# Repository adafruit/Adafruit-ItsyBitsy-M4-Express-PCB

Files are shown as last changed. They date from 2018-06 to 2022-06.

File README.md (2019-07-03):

## Adafruit ItsyBitsy M4 Express PCB

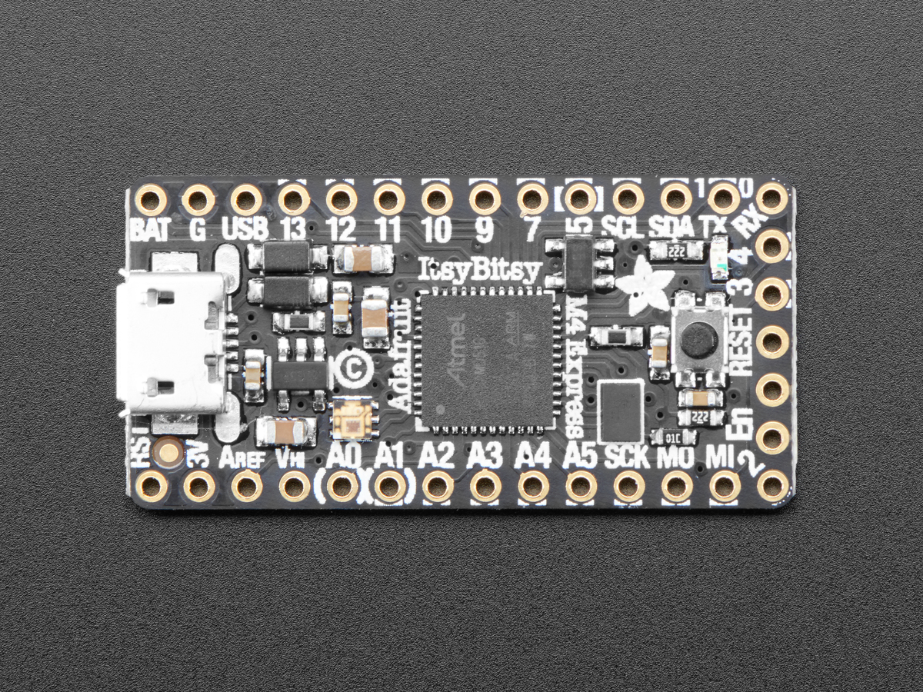
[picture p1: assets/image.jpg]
<a href="http://www.adafruit.com/products/3800"><br/>
Click here to purchase one from the Adafruit shop</a>

PCB files for the Adafruit ItsyBitsy M4 Express. PCB format is EagleCAD schematic and board layout

For more details, check out the product pages at
* https://www.adafruit.com/products/3800

### Description

What's smaller than a Feather but larger than a Trinket? It's an Adafruit ItsyBitsy M4 Express featuring the Microchip ATSAMD51! Small, powerful, with a ultra fast ATSAMD51 Cortex M4 processor running at 120 MHz - this microcontroller board is perfect when you want something very compact, with a ton of horsepower and a bunch of pins. This Itsy is like a bullet train, with it's 120MHz Cortex M4 with floating point support and 512KB Flash and 192KB RAM. Your code will zig and zag and zoom, and with a bunch of extra peripherals for support, this will for sure be your favorite new chipset.

ItsyBitsy M4 Express is only 1.4" long by 0.7" wide, but has 6 power pins, 23 digital GPIO pins (7 of which can be analog in, 2 x 1 MSPS analog out DACs, and 18 x PWM out). It's the same chip as the Adafruit Metro M4 but really really small. So it's great once you've finished up a prototype on a Metro M4 or (the upcoming) Feather M4, and want to make the project much smaller. It even comes with 2MB of SPI Flash built in, for data logging, file storage, or CircuitPython code.

The most exciting part of the ItsyBitsy M4 is that while you can use it with the Arduino IDE, we are shipping it with CircuitPython on board. When you plug it in, it will show up as a very small disk drive with main.py on it. Edit main.py with your favorite text editor to build your project using Python, the most popular programming language. No installs, IDE or compiler needed, so you can use it on any computer, even ChromeBooks or computers you can't install software on. When you're done, unplug the Itsy' and your code will go with you.

### License

Adafruit invests time and resources providing this open source design, please support Adafruit and open-source hardware by purchasing products from [Adafruit](https://www.adafruit.com)!

Designed by Limor Fried/Ladyada for Adafruit Industries.

Creative Commons Attribution/Share-Alike, all text above must be included in any redistribution. See license.txt for additional details.

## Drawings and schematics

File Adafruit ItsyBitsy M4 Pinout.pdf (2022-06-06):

# Adafruit ItsyBitsy M4

# https://www.adafruit.com/product/3800

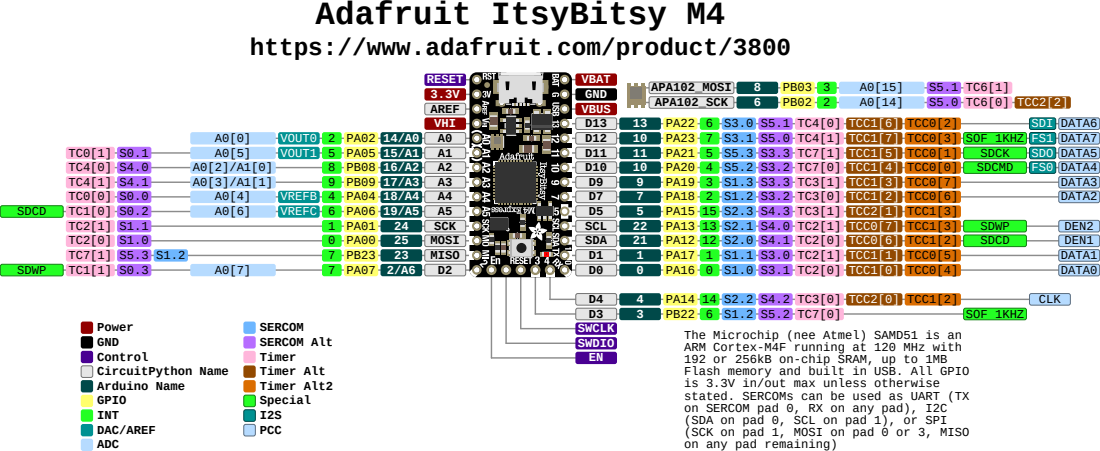
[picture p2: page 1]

The Microchip (nee Atmel) SAMD51 is an
ARM Cortex-M4F running at 120 MHz with
192 or 256kB on-chip SRAM, up to 1MB
Flash memory and built in USB. All GPIO
is 3.3V in/out max unless otherwise
stated. SERCOMs can be used as UART (TX
on SERCOM pad 0, RX on any pad), I2C
(SDA on pad 0, SCL on pad 1), or SPI
(SCK on pad 1, MOSI on pad 0 or 3, MISO
on any pad remaining)

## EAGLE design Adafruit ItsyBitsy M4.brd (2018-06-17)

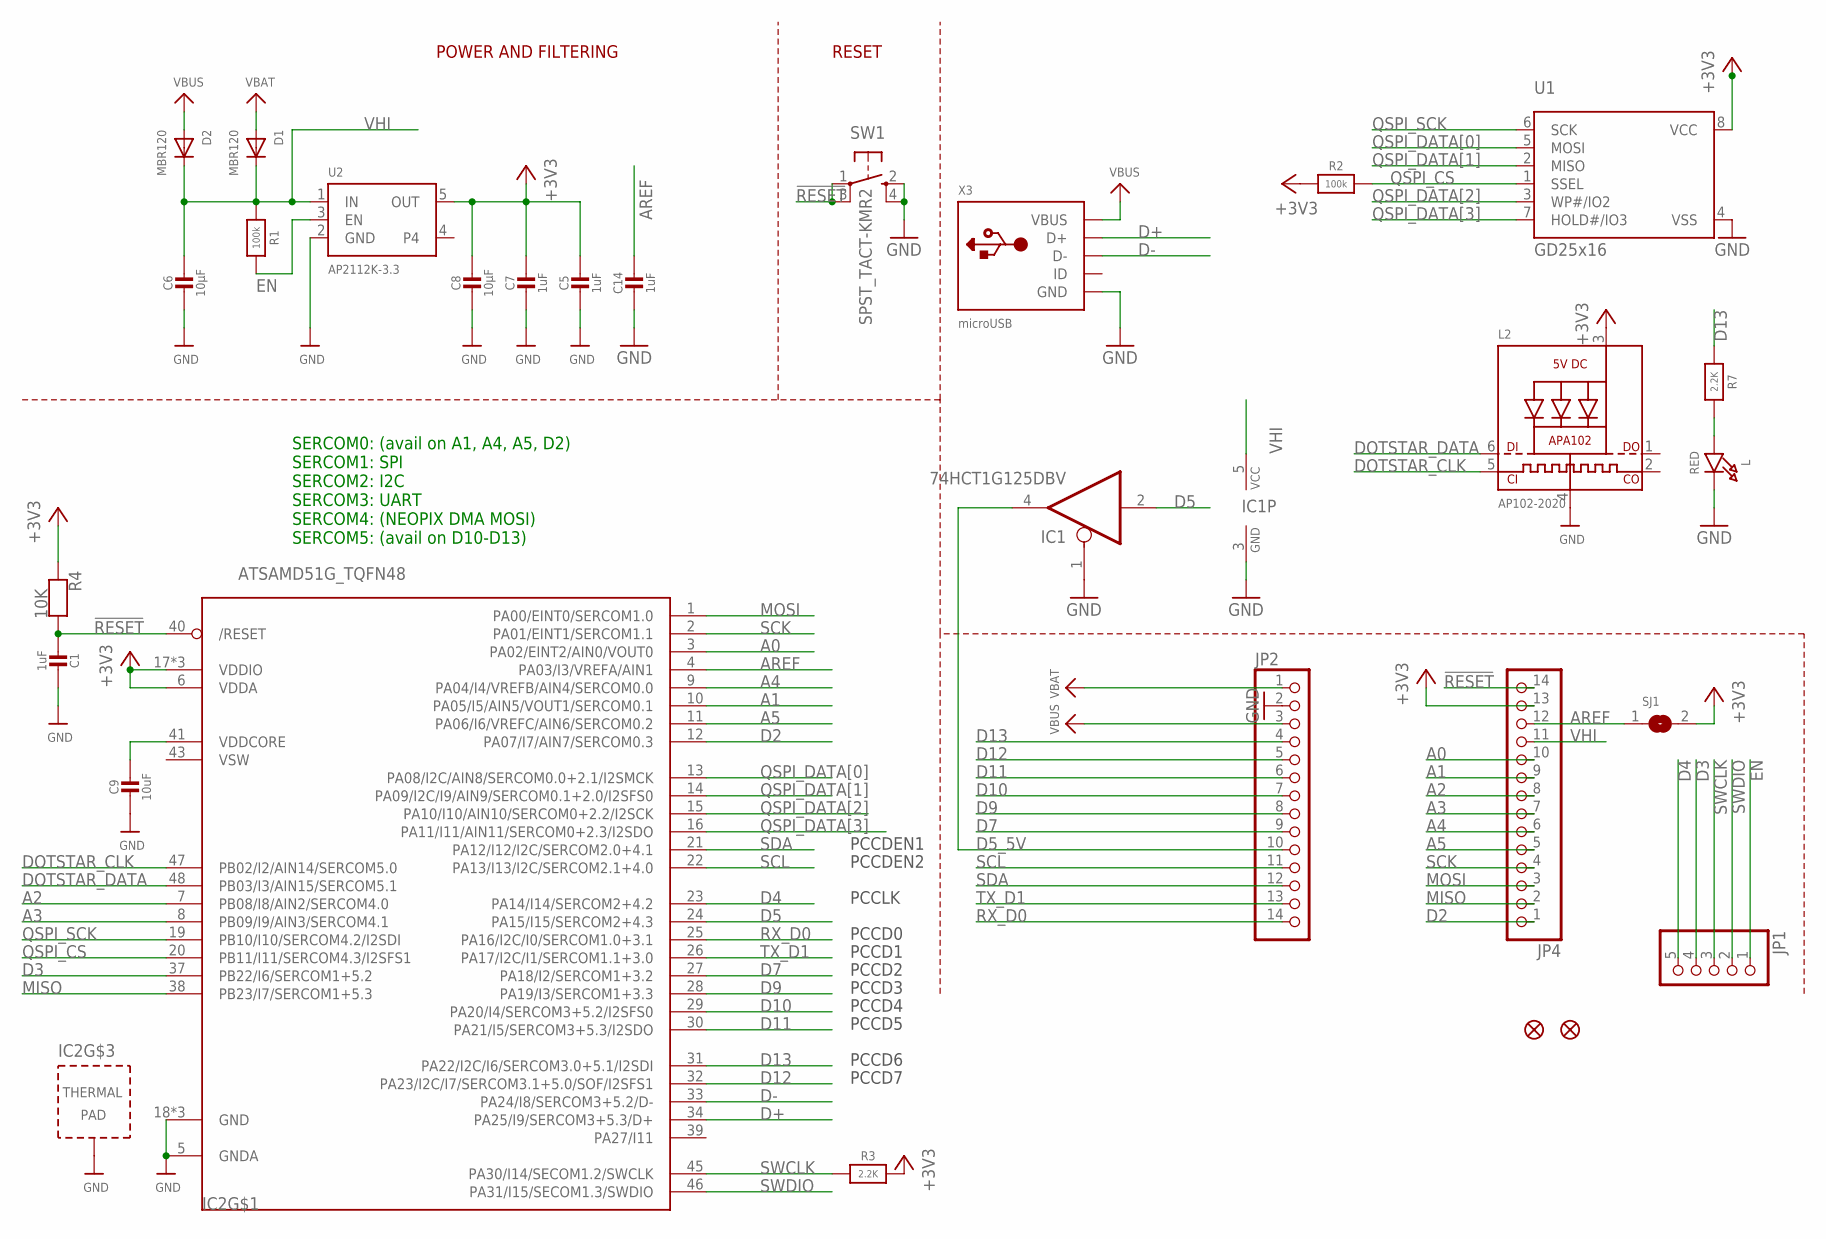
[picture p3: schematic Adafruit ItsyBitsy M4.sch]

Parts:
C1: 1uF; _0603MP
C5, C7, C14: 1uF; 0603-NO
C6, C8: 10µF; 0805-NO
C9: 10uF; _0805MP
D1, D2: MBR120; SOD-123FL
IC1: 74HCT1G125DBV; SOT23-5
IC2: ATSAMD51G_TQFN48; TQFN48_7MM
JP1: HEADER-1X570MIL; 1X05_ROUND_70
JP2, JP4: HEADER-1X14; 1X14_ROUND70
L: RED; CHIPLED_0603_NOOUTLINE
L2: AP102-2020; APA102_2020
R1, R2: 100k; 0603-NO
R3: 2.2K; _0603MP
R4: 10K; _0603MP
R7: 2.2K; 0603-NO
SJ1: SOLDERJUMPERCLOSED; SOLDERJUMPER_CLOSEDWIRE
SW1: SPST_TACT-KMR2; KMR2
U1: GD25x16; USON8
U2: AP2112K-3.3; SOT23-5
U$34, U$35: FIDUCIAL_1MM
X3: microUSB; 4UCONN_20329_V2

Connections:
!RESET: C1.2, IC2.40 (/RESET), JP4.14, R4.2, SW1.1, SW1.3 (P1)
+3V3: C5.1, C7.1, C8.1, IC2.6 (VDDA), IC2.17 (VDDIO), IC2.36 (VDDIO), IC2.44 (VDDIO), JP4.13, L2.3 (VDD), R2.1, R3.2, R4.1, SJ1.2, U1.8 (VCC), U2.5 (OUT)
A0: IC2.3 (PA02/EINT2/AIN0/VOUT0), JP4.10
A1: IC2.10 (PA05/I5/AIN5/VOUT1/SERCOM0.1), JP4.9
A2: IC2.7 (PB08/I8/AIN2/SERCOM4.0), JP4.8
A3: IC2.8 (PB09/I9/AIN3/SERCOM4.1), JP4.7
A4: IC2.9 (PA04/I4/VREFB/AIN4/SERCOM0.0), JP4.6
A5: IC2.11 (PA06/I6/VREFC/AIN6/SERCOM0.2), JP4.5
AREF: C14.1, IC2.4 (PA03/I3/VREFA/AIN1), JP4.12, SJ1.1
D2: IC2.12 (PA07/I7/AIN7/SERCOM0.3), JP4.1
D3: IC2.37 (PB22/I6/SERCOM1+5.2), JP1.4
D4: IC2.23 (PA14/I14/SERCOM2+4.2), JP1.5
D5: IC1.2 (I), IC2.24 (PA15/I15/SERCOM2+4.3)
D5_5V: IC1.4 (O), JP2.10
D7: IC2.27 (PA18/I2/SERCOM1+3.2), JP2.9
D9: IC2.28 (PA19/I3/SERCOM1+3.3), JP2.8
D10: IC2.29 (PA20/I4/SERCOM3+5.2/I2SFS0), JP2.7
D11: IC2.30 (PA21/I5/SERCOM3+5.3/I2SDO), JP2.6
D12: IC2.32 (PA23/I2C/I7/SERCOM3.1+5.0/SOF/I2SFS1), JP2.5
D13: IC2.31 (PA22/I2C/I6/SERCOM3.0+5.1/I2SDI), JP2.4, R7.1
D+: IC2.34 (PA25/I9/SERCOM3+5.3/D+), X3.D+
D-: IC2.33 (PA24/I8/SERCOM3+5.2/D-), X3.D-
DOTSTAR_CLK: IC2.47 (PB02/I2/AIN14/SERCOM5.0), L2.5 (CKI)
DOTSTAR_DATA: IC2.48 (PB03/I3/AIN15/SERCOM5.1), L2.6 (DI)
EN: JP1.1, R1.2, U2.3 (EN)
GND: C1.1, C5.2, C6.2, C7.2, C8.2, C9.2, C14.2, IC1.1 (OE), IC1.3 (GND), IC2.5 (GNDA), IC2.18 (GND), IC2.35 (GND), IC2.42 (GND), IC2.THERMAL (TP), JP2.2, L.C, L2.4 (GND), SW1.2 (S), SW1.4 (S1), U1.4 (VSS), U2.2 (GND), X3.BASE@1 (GND), X3.BASE@2 (GND), X3.GND, X3.SPRT@1 (GND), X3.SPRT@2 (GND), X3.SPRT@3 (GND), X3.SPRT@4 (GND)
MISO: IC2.38 (PB23/I7/SERCOM1+5.3), JP4.2
MOSI: IC2.1 (PA00/EINT0/SERCOM1.0), JP4.3
unnamed: L.A, R7.2
QSPI_CS: IC2.20 (PB11/I11/SERCOM4.3/I2SFS1), R2.2, U1.1 (SSEL)
QSPI_DATA[0]: IC2.13 (PA08/I2C/AIN8/SERCOM0.0+2.1/I2SMCK), U1.5 (MOSI)
QSPI_DATA[1]: IC2.14 (PA09/I2C/I9/AIN9/SERCOM0.1+2.0/I2SFS0), U1.2 (MISO)
QSPI_DATA[2]: IC2.15 (PA10/I10/AIN10/SERCOM0+2.2/I2SCK), U1.3 (WP#/IO2)
QSPI_DATA[3]: IC2.16 (PA11/I11/AIN11/SERCOM0+2.3/I2SDO), U1.7 (HOLD#/IO3)
QSPI_SCK: IC2.19 (PB10/I10/SERCOM4.2/I2SDI), U1.6 (SCK)
RX_D0: IC2.25 (PA16/I2C/I0/SERCOM1.0+3.1), JP2.14
SCK: IC2.2 (PA01/EINT1/SERCOM1.1), JP4.4
SCL: IC2.22 (PA13/I13/I2C/SERCOM2.1+4.0), JP2.11
SDA: IC2.21 (PA12/I12/I2C/SERCOM2.0+4.1), JP2.12
SWCLK: IC2.45 (PA30/I14/SECOM1.2/SWCLK), JP1.3, R3.1
SWDIO: IC2.46 (PA31/I15/SECOM1.3/SWDIO), JP1.2
TX_D1: IC2.26 (PA17/I2C/I1/SERCOM1.1+3.0), JP2.13
VBAT: D1.A, JP2.1
VBUS: D2.A, JP2.3, X3.VBUS
VDDCORE: C9.1, IC2.41 (VDDCORE)
VHI: C6.1, D1.C, D2.C, IC1.5 (VCC), JP4.11, R1.1, U2.1 (IN)
VSW: IC2.43 (VSW)

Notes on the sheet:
POWER AND FILTERING
RESET
SERCOM0: (avail on A1, A4, A5, D2) SERCOM1: SPI SERCOM2: I2C SERCOM3: UART SERCOM4: (NEOPIX DMA MOSI) SERCOM5: (avail on D10-D13)
PCCDEN1
PCCDEN2
PCCD0
PCCD1
PCCD2
PCCD3
PCCD4
PCCD5
PCCD6
PCCD7
PCCLK

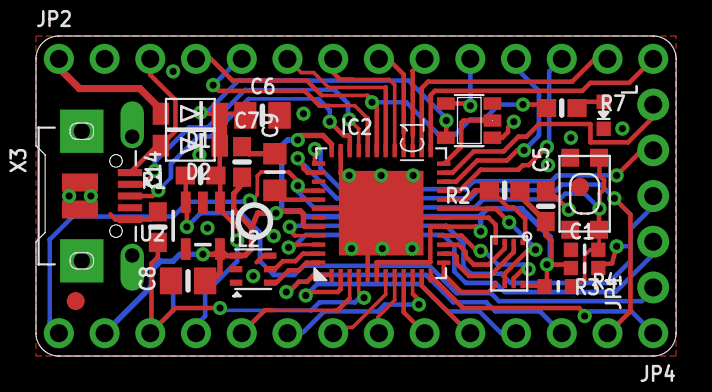
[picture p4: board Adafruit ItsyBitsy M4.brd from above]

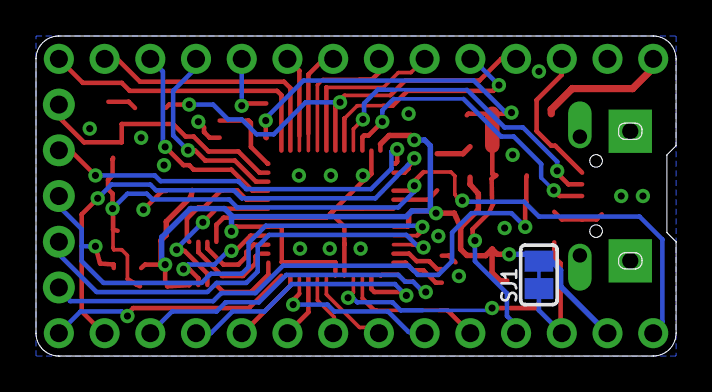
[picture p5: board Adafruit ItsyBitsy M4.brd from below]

Board: 2 copper layers, 35.6 x 17.8 mm, 31 parts (2 on the bottom side), 46 nets.

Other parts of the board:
U$4: ITSYM4_TOP
U$5: ITSYM4_BOT
U$6: PCBFEAT-REV-040

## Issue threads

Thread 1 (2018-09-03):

Dotstar LED and SERCOM5

MartinL1, 2018-09-03:
First of all thank you for the Itsy Bitsy M4, it's a great board.

Rather than using your Dotstar Library, I decided to control the LED by simply configuring SERCOM5 as a SPI port, but quickly ran into trouble.

It appears in the Itsy Bitsy schematic that the Dotstar clock has been connected to port pin PB02 (SERCOM5/PAD[0]) and data to PB03 (SERCOM5/PAD[1]). Unfortunately the SAMD51's SERCOMs cannot be configured for a clock on PAD[0] and data on PAD[1].

Unless I'm mistaken, this means that it's necessary to bit-bang the Dotstar's control lines. If the data and clock pins were reversed, it would have allowed for hardware SPI control with SERCOM5. Same goes for the Itsy Bitsy M0 on SERCOM1.

ladyada, 2018-09-04:
yep - the routing was too tight for other way and also it seemed a shame to waste a sercom on one pixel when all our drivers support bitbanging :)

Closed 2018-09-04.

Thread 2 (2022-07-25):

In the pinout table for the ItsyBitsy M4, the D12 Arduino name is wrong

MichaelMeissner, 2022-07-25:
In the pinout page for the ItsyBitsy M4 ([ItsyBitsy M4 pinout](https://learn.adafruit.com/introducing-adafruit-itsybitsy-m4/pinouts)) the 5th pin on the right side from the top has the wrong Arduino name.

The pinout lists the pin to have an Arduino name of '10'.  However, '10' is used two rows down.  It should have the Arduino name of '12' to match the CircuitPython name of D12, and the text on the PCB.  I had code reading from pin 10, and it didn't work until I changed it to 12 on the ItsyBitsy M4 Express.

ladyada, 2022-08-02:
hmm - this looks ok to us? can you point out he error and we'll fix :)
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

evaherrada, 2022-08-02:
Ah yeah I see it. Will add to my list

nomadbyte, 2023-06-16:
Yep, still a problem. D12 should be 12 (not 10)

In case anyone needs it, attached is a .png image with the corrected pinout.

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

evaherrada, 2023-06-16:
Will get this done very soon

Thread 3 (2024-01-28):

Please add Arduino support for Serial2, Serial3, etc, on the M4 Express boards

Andy2No, 2024-01-28:
This have been discussed several times in the Adafruit forum, and appears to still be unresolved.  There is apparently no definition for Serial2, Serial3 etc, for these board variants, and no documentation on how to make them work, despite there being configurable SERCOMs that should support them.

For example, search the forum for the words;

 M4 Serial2

Here's a search link to do that:

https://forums.adafruit.com/search.php?keywords=serial2+m4&sort=BestMatch

dhalbert, 2024-01-28:
Have you seen this: https://learn.adafruit.com/using-atsamd21-sercom-to-add-more-spi-i2c-serial-ports ?

Andy2No, 2024-01-28:
I hadn't.  Thanks.  I'm still not clear how to apply it to each particular M4 board Adafruit makes though, and I'm not clear why Serial was redefined, on the second page, instead of defining Serial2.  Is there a reason for that?;

https://learn.adafruit.com/using-atsamd21-sercom-to-add-more-spi-i2c-serial-ports/muxing-it-up

Apart from the individual board and chip details, the recommendation seems to be for us to produce new variants, with the added feature.  Perhaps I'm misunderstanding that part.

I would hope that us mere mortals would have the opportunity to just define a new Serial object with a pair of valid pins, e.g. just using this line from that page, but with a more sensible name;

Uart Serial2( &sercom5, PIN_SERIAL_RX, PIN_SERIAL_TX, PAD_SERIAL_RX, PAD_SERIAL_TX ) ;

Is that possible?  If so, perhaps all that's needed is a new page of documentation that relates to the current M4 boards, with a table of details for each one.

It would be nice to have a table clearly stating which pins can be used for each board too.

dhalbert, 2024-01-28:
> Uart Serial2( &sercom5, PIN_SERIAL_RX, PIN_SERIAL_TX, PAD_SERIAL_RX, PAD_SERIAL_TX ) ;

That kind of example is give in https://learn.adafruit.com/using-atsamd21-sercom-to-add-more-spi-i2c-serial-ports/creating-a-new-serial. There is also discussion on that page of the SAMD51.

The problem is that the correspondence between pins, pads, and functionality on the SAMD boards is not very regular at all. Also, since SERCOMs can also do I2C, etc. you may end up blocking out some pins, but only because you've chosen _other_ pins to do other functions. It's very interlocking and not predictable without looking at pinmux tables.

You can do that by hand. You can also use the CircuitPython program given here https://learn.adafruit.com/circuitpython-essentials/circuitpython-uart-serial#wheres-my-uart-2985036 to give you an idea of which pins to use, but you'll still need to specify the pads.

CircuitPython allocates the SERCOMs dynamically, but it can also run into interlocking assignment difficulties because of the order in which it chooses SERCOMs: https://learn.adafruit.com/circuitpython-essentials/circuitpython-uart-serial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

Other chips like the nRF52840 and the ESP line have a full or almost full crossbar, so you can use almost any pin for anything.

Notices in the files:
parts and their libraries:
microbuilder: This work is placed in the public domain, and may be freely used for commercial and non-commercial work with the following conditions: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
